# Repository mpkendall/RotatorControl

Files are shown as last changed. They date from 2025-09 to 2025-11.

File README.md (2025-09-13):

# Controller for the STARS Rotator
## For use with the Yaesu G-5500DC rotator with custom PCB

## Development
```mv config.h.example config.h```

Fill in your configuration (notably WiFi settings).

Upload code through Arduino to the ESP-32!

*README is a work-in-progress.*
*Licensed under MIT license*

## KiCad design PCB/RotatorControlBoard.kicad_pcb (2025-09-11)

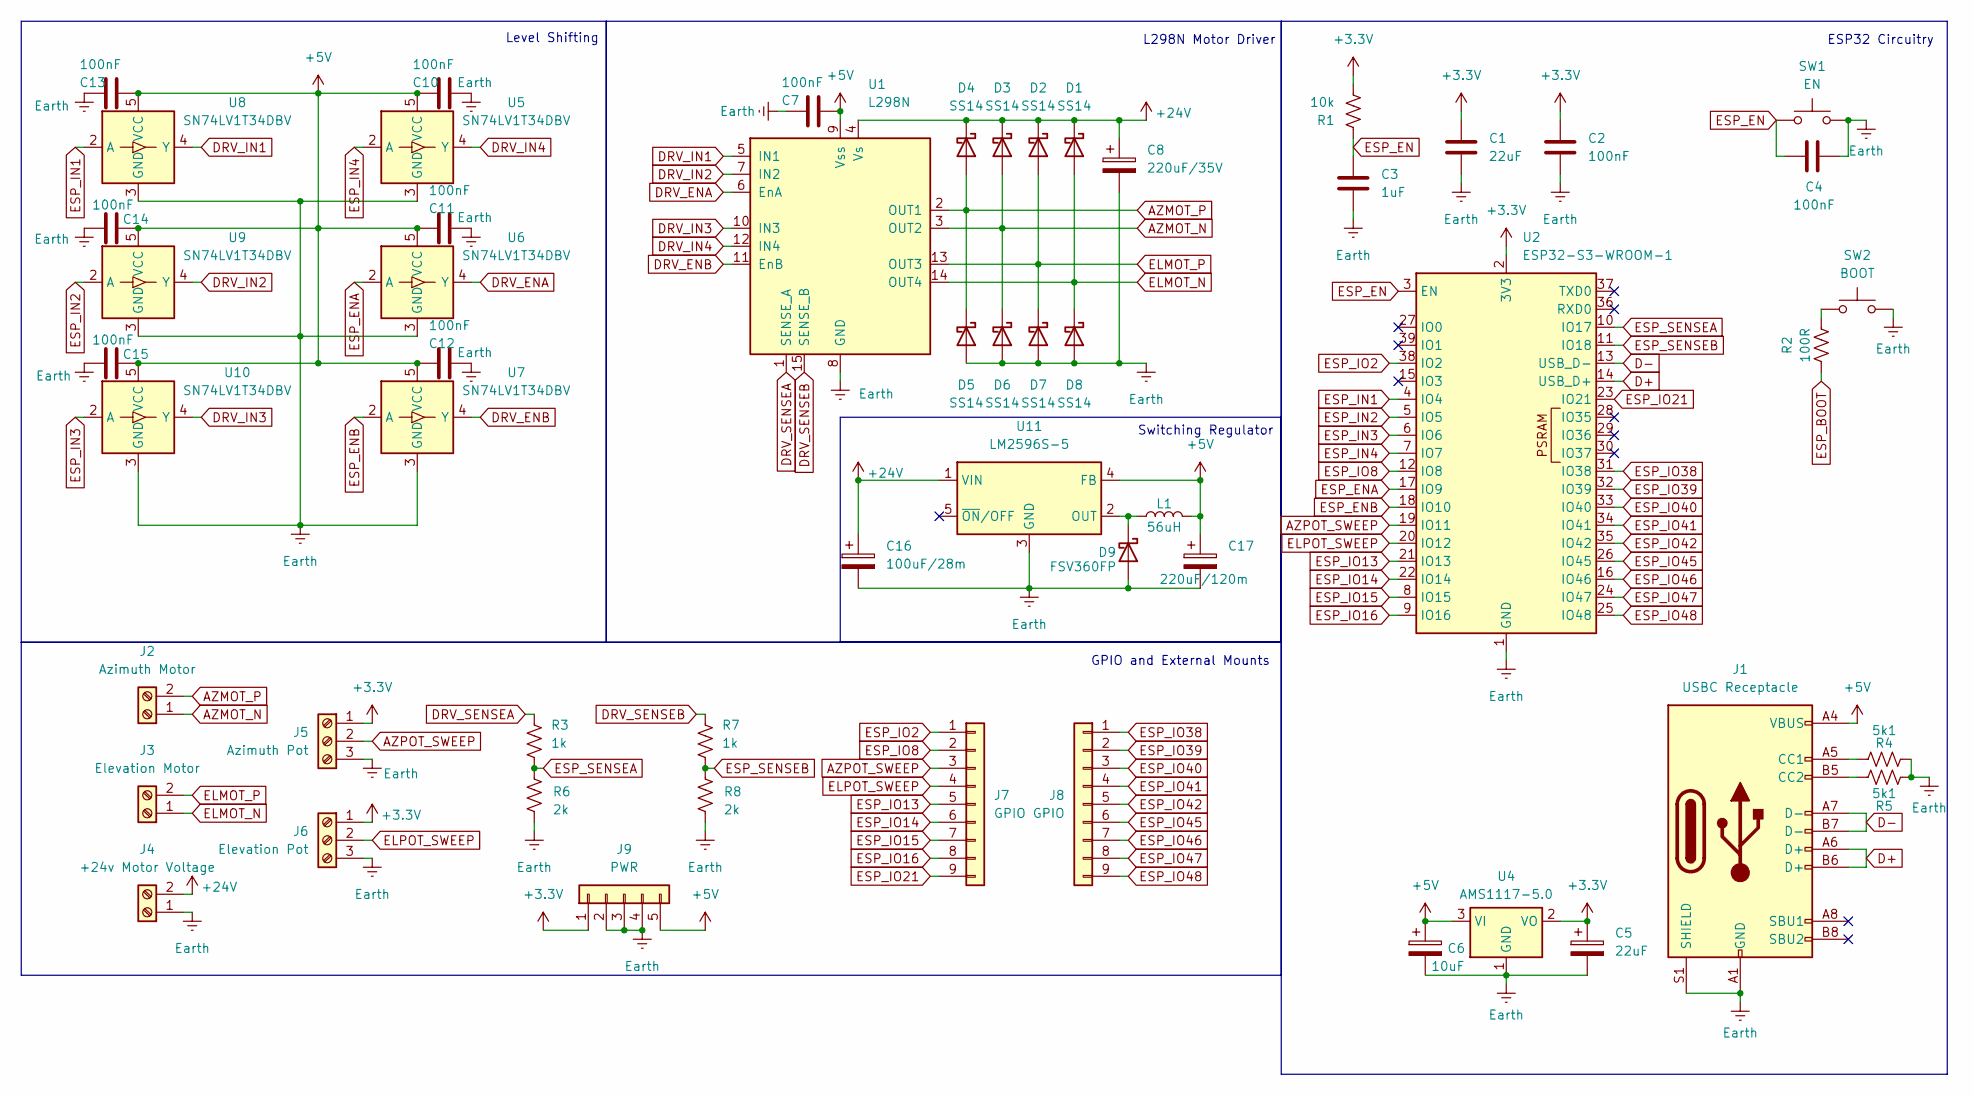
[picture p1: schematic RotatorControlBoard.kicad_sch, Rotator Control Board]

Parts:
C1, C5: 22uF; C_0805_2012Metric
C2, C4, C7, C10, C11, C12, C13, C14, C15: 100nF; C_0805_2012Metric
C3: 1uF; C_0805_2012Metric
C6: 10uF; C_0805_2012Metric
C8: 220uF/35V; CAP_EEE1VA221UP
C16: 100uF/28m; PCAP_EEHZ_G_PAN
C17: 220uF/120m; U2-P_NCH
D1, D2, D3, D4, D5, D6, D7, D8: SS14; D_SMA
D9: FSV360FP; B360A-13-F_DIO
J1: USBC Receptacle; USB_C_Receptacle_GCT_USB4105-xx-A_16P_TopMnt_Horizontal
J2: Azimuth Motor; TerminalBlock_MaiXu_MX126-5.0-02P_1x02_P5.00mm
J3: Elevation Motor; TerminalBlock_MaiXu_MX126-5.0-02P_1x02_P5.00mm
J4: +24v Motor Voltage; TerminalBlock_MaiXu_MX126-5.0-02P_1x02_P5.00mm
J5: Azimuth Pot; TerminalBlock_MaiXu_MX126-5.0-03P_1x03_P5.00mm
J6: Elevation Pot; TerminalBlock_MaiXu_MX126-5.0-03P_1x03_P5.00mm
J7, J8: GPIO; PinSocket_1x09_P2.54mm_Vertical
J9: PWR; PinHeader_1x05_P2.54mm_Vertical
L1: 56uH; IND_IHLP-6767GZ_VIS
R1: 10k; R_0805_2012Metric
R2: 100R; R_0805_2012Metric
R3, R7: 1k; R_0805_2012Metric
R4, R5: 5k1; R_0805_2012Metric
R6, R8: 2k; R_0805_2012Metric
SW1: EN; SW_PUSH_6mm
SW2: BOOT; SW_PUSH_6mm
U1: L298N; TO-220-15_P2.54x2.54mm_StaggerOdd_Lead4.58mm_Vertical
U2: ESP32-S3-WROOM-1
U4: AMS1117-5.0; SOT-223-3_TabPin2
U5, U6, U7, U8, U9, U10: SN74LV1T34DBV; SOT-23-5
U11: LM2596S-5; TO-263-5_TabPin3

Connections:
+3.3V: C1.1, C2.1, C5.1, J5.1, J6.1, J9.1, R1.2, U2.2 (3V3), U4.2 (VO)
+5V: C6.1, C7.1, C10.2, C11.2, C12.2, C13.1, C14.1, C15.1, C17.1, J1.A4 (VBUS), J1.A9 (VBUS), J1.B4 (VBUS), J1.B9 (VBUS), J9.5, L1.2, U1.9 (Vss), U4.3 (VI), U5.5 (VCC), U6.5 (VCC), U7.5 (VCC), U8.5 (VCC), U9.5 (VCC), U10.5 (VCC), U11.4 (FB)
+24V: C8.1, C16.1, D1.1 (K), D2.1 (K), D3.1 (K), D4.1 (K), J4.2, U1.4 (Vs), U11.1 (VIN)
AZMOT_N: D3.2 (A), D6.1 (K), J2.1, U1.3 (OUT2)
AZMOT_P: D4.2 (A), D5.1 (K), J2.2, U1.2 (OUT1)
AZPOT_SWEEP: J5.2, J7.3, U2.19 (IO11)
D+: J1.A6 (D+), J1.B6 (D+), U2.14 (USB_D+)
D-: J1.A7 (D-), J1.B7 (D-), U2.13 (USB_D-)
DRV_ENA: U1.6 (EnA), U6.4 (Y)
DRV_ENB: U1.11 (EnB), U7.4 (Y)
DRV_IN1: U1.5 (IN1), U8.4 (Y)
DRV_IN2: U1.7 (IN2), U9.4 (Y)
DRV_IN3: U1.10 (IN3), U10.4 (Y)
DRV_IN4: U1.12 (IN4), U5.4 (Y)
DRV_SENSEA: R3.1, U1.1 (SENSE_A)
DRV_SENSEB: R7.1, U1.15 (SENSE_B)
ELMOT_N: D1.2 (A), D8.1 (K), J3.1, U1.14 (OUT4)
ELMOT_P: D2.2 (A), D7.1 (K), J3.2, U1.13 (OUT3)
ELPOT_SWEEP: J6.2, J7.4, U2.20 (IO12)
ESP_BOOT: R2.2
ESP_EN: C3.1, C4.1, R1.1, SW1.1, U2.3 (EN)
ESP_ENA: U2.17 (IO9), U6.2 (A)
ESP_ENB: U2.18 (IO10), U7.2 (A)
ESP_IN1: U2.4 (IO4), U8.2 (A)
ESP_IN2: U2.5 (IO5), U9.2 (A)
ESP_IN3: U2.6 (IO6), U10.2 (A)
ESP_IN4: U2.7 (IO7), U5.2 (A)
ESP_IO2: J7.1, U2.38 (IO2)
ESP_IO8: J7.2, U2.12 (IO8)
ESP_IO13: J7.5, U2.21 (IO13)
ESP_IO14: J7.6, U2.22 (IO14)
ESP_IO15: J7.7, U2.8 (IO15)
ESP_IO16: J7.8, U2.9 (IO16)
ESP_IO21: J7.9, U2.23 (IO21)
ESP_IO38: J8.1, U2.31 (IO38)
ESP_IO39: J8.2, U2.32 (IO39)
ESP_IO40: J8.3, U2.33 (IO40)
ESP_IO41: J8.4, U2.34 (IO41)
ESP_IO42: J8.5, U2.35 (IO42)
ESP_IO45: J8.6, U2.26 (IO45)
ESP_IO46: J8.7, U2.16 (IO46)
ESP_IO47: J8.8, U2.24 (IO47)
ESP_IO48: J8.9, U2.25 (IO48)
ESP_SENSEA: R3.2, R6.1, U2.10 (IO17)
ESP_SENSEB: R7.2, R8.1, U2.11 (IO18)
Earth: C1.2, C2.2, C3.2, C4.2, C5.2, C6.2, C7.2, C8.2, C10.1, C11.1, C12.1, C13.2, C14.2, C15.2, C16.2, C17.2, D5.2 (A), D6.2 (A), D7.2 (A), D8.2 (A), D9.2 (A), J1.A1 (GND), J1.A12 (GND), J1.B1 (GND), J1.B12 (GND), J1.S1 (SHIELD), J4.1, J5.3, J6.3, J9.2, J9.3, J9.4, R4.1, R5.1, R6.2, R8.2, SW1.2, SW2.2, U1.8 (GND), U2.1 (GND), U2.40 (GND), U2.41 (GND), U4.1 (GND), U5.3 (GND), U6.3 (GND), U7.3 (GND), U8.3 (GND), U9.3 (GND), U10.3 (GND), U11.3 (GND)
unnamed: D9.1 (K), L1.1, U11.2 (OUT)
unnamed: J1.A5 (CC1), R4.2
unnamed: J1.B5 (CC2), R5.2
unnamed: R2.1, SW2.1

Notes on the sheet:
L298N Motor Driver
Switching Regulator
Level Shifting
ESP32 Circuitry
GPIO and External Mounts

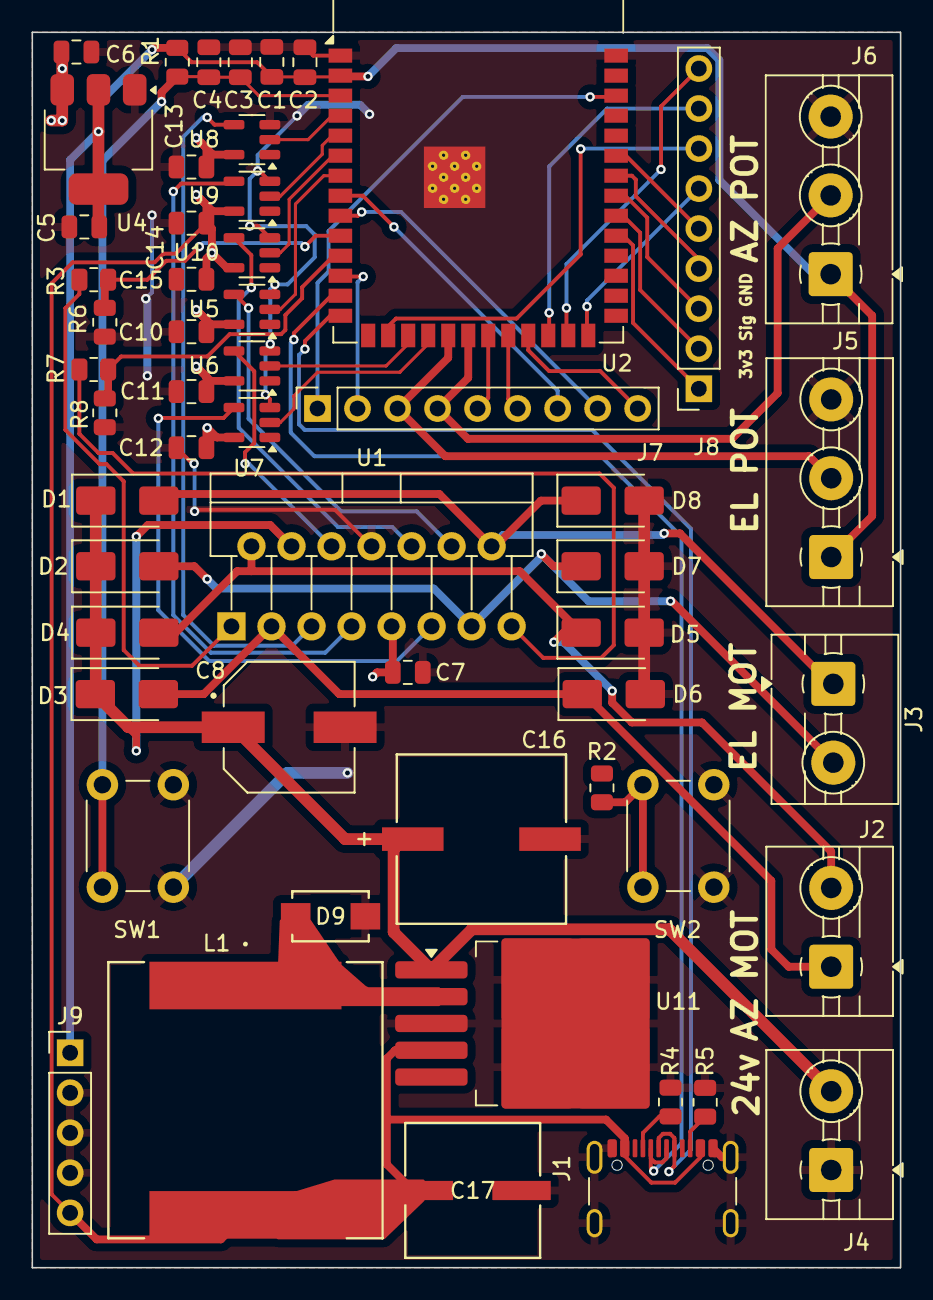
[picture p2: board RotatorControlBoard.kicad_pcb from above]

Board: 2 copper layers, 55.1 x 78.4 mm, 55 parts (0 on the bottom side), 49 nets.

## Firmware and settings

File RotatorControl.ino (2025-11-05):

// STARS Rotator Control Board

#include <WiFi.h>
#include <WebServer.h>
#include "config.h"
#include "motor.h"

WebServer server(80);

int az_limit_min = POT_AZ_LIMIT_MIN;
int az_limit_max = POT_AZ_LIMIT_MAX;
int el_limit_min = POT_EL_LIMIT_MIN;
int el_limit_max = POT_EL_LIMIT_MAX;

MotorControl azimuthMotor(M1P1, M1P2, ENA, AZPOT, POT_AZ_MIN, POT_AZ_MAX, az_limit_min, az_limit_max);
MotorControl elevationMotor(M2P1, M2P2, ENB, ELPOT, POT_EL_MIN, POT_EL_MAX, el_limit_min, el_limit_max);

Direction motorDirection;

int targetAzimuth = -1;
int targetElevation = -1;

// forward declaration: explicit prototype avoids Arduino auto-prototype issues with default args
void setMotorCoords(int targetAz, int targetEl, float slew = -1.0f);

// Simple bearer token check for all endpoints. Returns true if authorized.
bool checkAuth() {
  // If no token configured, deny access (require token).
  String expected = String("Bearer ") + String(BEARER_TOKEN);
  if (!server.hasHeader("Authorization")) {
    server.send(401, "text/plain", "Unauthorized");
    return false;
  }
  String auth = server.header("Authorization");
  if (auth != expected) {
    server.send(401, "text/plain", "Unauthorized");
    return false;
  }
  return true;
}

void setup() {
  azimuthMotor.begin();
  elevationMotor.begin();

  Serial.begin(115200);
  Serial.println("NEST Rotator Controller");
  WiFi.begin(SSID, PASS);
  while (WiFi.status() != WL_CONNECTED) {
    delay(500);
    Serial.print(".");
  }
  Serial.println("\nWiFi connected. IP address: ");
  Serial.println(WiFi.localIP());

  server.on("/", handleRoot);
  server.on("/command", handleCommand);
  server.on("/calibrate", handleCalibrate);
  server.on("/status", []() {
    if (!checkAuth()) return;
    Bearing b = getCurrentBearing();
    float azSpeed = azimuthMotor.getSpeed();
    float elSpeed = elevationMotor.getSpeed();
    String status = "Azimuth: " + String(b.azimuth) + " (" + String(azSpeed, 2) + " deg/s), ";
    status += "Elevation: " + String(b.elevation) + " (" + String(elSpeed, 2) + " deg/s)";
    server.send(200, "text/plain", status);
  });
  server.on("/ping", []() {
    if (!checkAuth()) return;
    server.send(200, "text/plain", "pong");
  });
  server.on("/test", handleSpeedTest);
  server.begin();
}

void loop() {
  server.handleClient();
  // update slew controllers (if active)
  azimuthMotor.update();
  elevationMotor.update();
  // run speed test sequence if active
  updateSpeedTest();
  if (targetAzimuth != -1 && targetElevation != -1) {
    Bearing current = getCurrentBearing();
    if (abs(current.azimuth - targetAzimuth) <= POSITION_THRESHOLD) {
      azimuthMotor.setDirection(stop);
    }
    if (abs(current.elevation - targetElevation) <= POSITION_THRESHOLD) {
      elevationMotor.setDirection(stop);
    }
  }
}

void updateMotorLimits() {
  azimuthMotor = MotorControl(M1P1, M1P2, ENA, AZPOT, POT_AZ_MIN, POT_AZ_MAX, az_limit_min, az_limit_max);
  elevationMotor = MotorControl(M2P1, M2P2, ENB, ELPOT, POT_EL_MIN, POT_EL_MAX, el_limit_min, el_limit_max);
}

void handleCalibrate() {
  if (!checkAuth()) return;
  bool updated = false;
  String msg = "";
  if (server.hasArg("az_limit_min")) {
    az_limit_min = server.arg("az_limit_min").toInt();
    updated = true;
  }
  if (server.hasArg("az_limit_max")) {
    az_limit_max = server.arg("az_limit_max").toInt();
    updated = true;
  }
  if (server.hasArg("el_limit_min")) {
    el_limit_min = server.arg("el_limit_min").toInt();
    updated = true;
  }
  if (server.hasArg("el_limit_max")) {
    el_limit_max = server.arg("el_limit_max").toInt();
    updated = true;
  }
  if (updated) {
    updateMotorLimits();
    msg = "Calibration updated. ";
  }
  msg += "az_limit_min=" + String(az_limit_min) + ", az_limit_max=" + String(az_limit_max);
  msg += ", el_limit_min=" + String(el_limit_min) + ", el_limit_max=" + String(el_limit_max);
  server.send(200, "text/plain", msg);
}

void handleRoot() {
  if (!checkAuth()) return;
  String html = "<!DOCTYPE html><html><head><title>Rotator Control</title></head><body>";
  html += "<h1>Rotator Control</h1>";
  html += "</body></html>";
  server.send(200, "text/html", html);
}

void handleCommand() {
  if (!checkAuth()) return;
  String az = server.arg("az");
  String el = server.arg("el");
  String slewArg = server.arg("slew");
  Serial.print("az=");
  Serial.print(az);
  Serial.print(", el=");
  Serial.println(el);

  if (!az.length() || !el.length()) {
    server.send(400, "text/plain", "Missing azimuth or elevation parameter");
    return;
  }
  int azVal = az.toInt();
  int elVal = el.toInt();
  bool azValid = (az == String(azVal));
  bool elValid = (el == String(elVal));
  if (!azValid || !elValid) {
    server.send(400, "text/plain", "Invalid azimuth or elevation value");
    return;
  }

  String response = "azimuth: " + az + ", elevation: " + el;
  // optional slew parameter (degrees per second). If not provided or invalid, pass -1 for full speed.
  float slewVal = -1.0f;
  if (slewArg.length()) {
    // toFloat returns 0.0 on failure; we accept zero as 'stop/change' so check string
    slewVal = slewArg.toFloat();
    // if slew is negative, treat as unspecified (full speed)
    if (slewVal <= 0.0f) slewVal = -1.0f;
  }
  targetAzimuth = azVal;
  targetElevation = elVal;
  setMotorCoords(targetAzimuth, targetElevation, slewVal);
  server.send(200, "text/plain", response);
}



Bearing getCurrentBearing() {
  Bearing b;
  b.azimuth = azimuthMotor.getBearing();
  b.elevation = elevationMotor.getBearing();
  return b;
}

// Speed test sequence state
unsigned long testStartMillis = 0;
int testPhase = 0;
bool testRunning = false;

void handleSpeedTest() {
  if (!checkAuth()) return;
  if (testRunning) {
    server.send(200, "text/plain", "Test already in progress");
    return;
  }
  testRunning = true;
  testPhase = 0;
  testStartMillis = millis();
  server.send(200, "text/plain", "Speed test started");
}

void updateSpeedTest() {
  if (!testRunning) return;
  
  unsigned long now = millis();
  unsigned long elapsed = now - testStartMillis;
  const unsigned long PHASE_DURATION = 5000; // 5 seconds per phase
  
  // Update test phase every PHASE_DURATION ms
  int currentPhase = elapsed / PHASE_DURATION;
  if (currentPhase != testPhase) {
    testPhase = currentPhase;
    // Test sequence:
    // 0: Stop both motors
    // 1: Az forward at 5 deg/s
    // 2: Az forward at 10 deg/s
    // 3: Az forward at full speed
    // 4: Az stop
    // 5: El up at 5 deg/s
    // 6: El up at 10 deg/s
    // 7: El up at full speed
    // 8: El stop, end test
    switch(testPhase) {
      case 0:
        azimuthMotor.setDirection(stop);
        elevationMotor.setDirection(stop);
        Serial.println("Test phase 0: All stop");
        break;
      case 1:
        azimuthMotor.setDirection(REVERSE_AZ ? backward : forward);
        azimuthMotor.setSlew(5.0f);
        Serial.println("Test phase 1: Az 5 deg/s");
        break;
      case 2:
        azimuthMotor.setSlew(10.0f);
        Serial.println("Test phase 2: Az 10 deg/s");
        break;
      case 3:
        azimuthMotor.clearSlew();
        Serial.println("Test phase 3: Az full speed");
        break;
      case 4:
        azimuthMotor.setDirection(stop);
        Serial.println("Test phase 4: Az stop");
        break;
      case 5:
        elevationMotor.setDirection(REVERSE_EL ? backward : forward);
        elevationMotor.setSlew(5.0f);
        Serial.println("Test phase 5: El 5 deg/s");
        break;
      case 6:
        elevationMotor.setSlew(10.0f);
        Serial.println("Test phase 6: El 10 deg/s");
        break;
      case 7:
        elevationMotor.clearSlew();
        Serial.println("Test phase 7: El full speed");
        break;
      case 8:
        elevationMotor.setDirection(stop);
        testRunning = false;
        Serial.println("Test phase 8: Test complete");
        break;
    }
  }
}

void setMotorCoords(int targetAz, int targetEl, float slew) {
  targetAz += AZ_OFFSET;
  targetEl += EL_OFFSET;
  if(targetAz > 360) targetAz -= 360;
  if(targetAz < 0) targetAz += 360;
  Bearing currentBearing = getCurrentBearing();
  if(targetAz > currentBearing.azimuth) {
    REVERSE_AZ ? azimuthMotor.setDirection(backward) : azimuthMotor.setDirection(forward);
    if (slew > 0) azimuthMotor.setSlew(slew); else azimuthMotor.clearSlew();
  } else if (targetAz < currentBearing.azimuth) {
    REVERSE_AZ ? azimuthMotor.setDirection(forward) :  azimuthMotor.setDirection(backward);
    if (slew > 0) azimuthMotor.setSlew(slew); else azimuthMotor.clearSlew();
  } else {
    azimuthMotor.setDirection(stop);
    azimuthMotor.clearSlew();
  }

  if(targetEl > 180) targetEl = 180;
  if(targetEl < 0) targetEl = 0;
  if(targetEl > currentBearing.elevation) {
    REVERSE_EL ? elevationMotor.setDirection(backward) : elevationMotor.setDirection(forward);
    if (slew > 0) elevationMotor.setSlew(slew); else elevationMotor.clearSlew();
  } else if (targetEl < currentBearing.elevation) {
    REVERSE_EL ? elevationMotor.setDirection(forward) : elevationMotor.setDirection(backward);
    if (slew > 0) elevationMotor.setSlew(slew); else elevationMotor.clearSlew();
  } else {
    elevationMotor.setDirection(stop);
    elevationMotor.clearSlew();
  }
}

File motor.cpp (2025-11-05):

#include "motor.h"

MotorControl::MotorControl(int pin1, int pin2, int enablePin, int potPin, int minRaw, int maxRaw, int minDegree, int maxDegree)
    : _pin1(pin1), _pin2(pin2), _enablePin(enablePin), _potPin(potPin), _minRaw(minRaw), _maxRaw(maxRaw), _minDegree(minDegree), _maxDegree(maxDegree) {}

void MotorControl::begin() {
    pinMode(_pin1, OUTPUT);
    pinMode(_pin2, OUTPUT);
    pinMode(_potPin, INPUT);
    pinMode(_enablePin, OUTPUT);
    // default enable to HIGH (full power) - update() may override for PWM
    digitalWrite(_enablePin, HIGH);
    stop();
}

void MotorControl::forward() {
    digitalWrite(_pin1, HIGH);
    digitalWrite(_pin2, LOW);
}

void MotorControl::backward() {
    digitalWrite(_pin1, LOW);
    digitalWrite(_pin2, HIGH);
}

void MotorControl::stop() {
    digitalWrite(_pin1, LOW);
    digitalWrite(_pin2, LOW);
    // disable motor output when stopped
    digitalWrite(_enablePin, LOW);
}

void MotorControl::setDirection(Direction direction) {
    switch (direction) {
        case 0:
            forward();
            break;
        case 1:
            backward();
            break;
        case 2:
            stop();
            break;
    }
}

int MotorControl::getBearing() {
    return map(ADC_LUT[analogRead(_potPin)], _minRaw, _maxRaw, _minDegree, _maxDegree);
}

void MotorControl::setSlew(float degreesPerSecond) {
    if (degreesPerSecond <= 0.0f) {
        clearSlew();
        return;
    }
    _desiredSlew = degreesPerSecond;
    _slewActive = true;
    _lastMeasuredBearing = getBearing();
    _lastMeasureMillis = millis();
    _duty = 1.0f; // start full on
    _pwmCycleStartMicros = micros();
}

void MotorControl::clearSlew() {
    _slewActive = false;
    _desiredSlew = 0.0f;
    _duty = 1.0f;
    // ensure enable pin is fully on when not slew-controlling
    digitalWrite(_enablePin, HIGH);
}

// periodic update: measure speed and PWM enable pin to approximate desired degrees/sec
void MotorControl::update() {
    if (!_slewActive) return;

    unsigned long nowMillis = millis();
    // measure every ~200ms
    const unsigned long measureInterval = 200;
    if (_lastMeasureMillis == 0) {
        _lastMeasureMillis = nowMillis;
        _lastMeasuredBearing = getBearing();
    }
    if (nowMillis - _lastMeasureMillis >= measureInterval) {
        int current = getBearing();
        int diff = current - _lastMeasuredBearing;
        int range = _maxDegree - _minDegree;
        // account for wrap-around
        if (abs(diff) > range / 2) {
            if (diff > 0) diff -= range;
            else diff += range;
        }
        float dt = (nowMillis - _lastMeasureMillis) / 1000.0f;
    float speed = 0.0f;
    if (dt > 0.0f) speed = diff / dt; // degrees per second
    // store last measured speed (absolute value)
    _lastMeasuredSpeed = fabs(speed);

        // control duty using a simple proportional controller on speed magnitude
        float error = _desiredSlew - fabs(speed);
        _duty += _kp * error;
        if (_duty > 1.0f) _duty = 1.0f;
        if (_duty < 0.0f) _duty = 0.0f;

        _lastMeasuredBearing = current;
        _lastMeasureMillis = nowMillis;
    }

    // software PWM on _enablePin using micros()
    unsigned long nowMicros = micros();
    unsigned long period = _pwmPeriodMicros;
    if (_pwmCycleStartMicros == 0) _pwmCycleStartMicros = nowMicros;
    unsigned long elapsed = nowMicros - _pwmCycleStartMicros;
    if (elapsed >= period) {
        // advance cycle start by integer number of periods to avoid drift
        unsigned long cycles = elapsed / period;
        _pwmCycleStartMicros += cycles * period;
        elapsed = nowMicros - _pwmCycleStartMicros;
    }
    unsigned long onTime = (unsigned long)(_duty * (float)period);
    if (onTime == 0) {
        digitalWrite(_enablePin, LOW);
    } else if (onTime >= period) {
        digitalWrite(_enablePin, HIGH);
    } else {
        if (elapsed < onTime) digitalWrite(_enablePin, HIGH);
        else digitalWrite(_enablePin, LOW);
    }
}

float MotorControl::getSpeed() {
    return _lastMeasuredSpeed;
}

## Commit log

2025-09-14 calibrated el
2025-11-01 Refactor motor control limits and add calibration endpoints
